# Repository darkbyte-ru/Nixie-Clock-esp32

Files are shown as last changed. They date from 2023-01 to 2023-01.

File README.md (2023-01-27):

# Idea

Original Nixie Clock KIT board contain **STM8S** (STM8S003F3) MCU, **74HC595** (SNx4HC595) shift registers, **ULN2003** darlington drivers, **DS3231** RTC with battery and plexiglass front-back covers. Also there are two buttons for setting the time and change some settings, which are resets after power cycle. 

First thought to keep an MCU and add external GPS/WiFi module to be able to sync time. But then I thought that I could simplify the task a little and completely replace MCU with an ESP32. S2 mini board perfectly fit for size and mounting holes. So a soldered out STM8 MCU and connect ESP32 board using lacquered copper wires.

# In-the-box picture

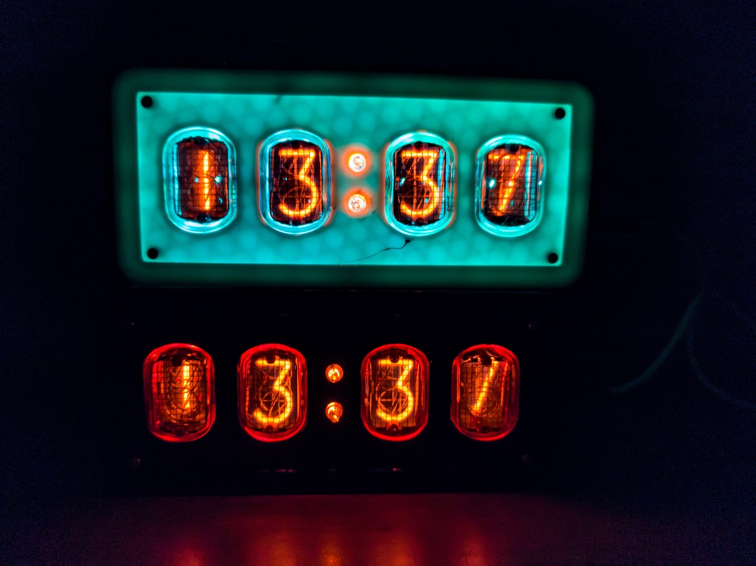
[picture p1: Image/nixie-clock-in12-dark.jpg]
nixie-stm8-pinout


# Hardware

- Nixie Clock IN12 DIY KIT (NixieClock_IN12 v4.2 board from [aliexpress](https://aliexpress.ru/wholesale?SearchText=nixie+clock+in12))
- IN-12 tubes (4pcs) with digits
- 3D printed case (I used [this one](https://www.printables.com/model/69286-in-12-nixie-clock-by-delucalabs))
- WeMos/Lolin S2 MINI ESP32 board
- RCWL-0516 microwave motion sensor

# Assembly

After researching original connection scheme, prepared next pinout: 

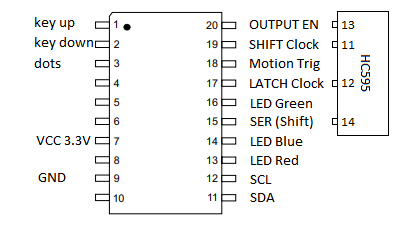
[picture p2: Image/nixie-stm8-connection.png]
nixie-stm8-pinout


I connected the most inputs to the one side of esp32 board and only KEYs wires goes to GPIO10 & 12. Used by me GPIOs can be found in the config.h file.

For test purpose I also connected 5V bus from ESP32 with 5V input of nixie board. Without that tube did not powered up when the only esp board powered.

To extend lamp life and save some electricity there is also **RCWL-0516** microwave motion sensor added (powered from 5V bus). By default it switch-off the tubes after 30 seconds of inactivity.

By default **DOTs** driven via separate transistor, but HC595 registers has left couple unused outputs, so thats possible to connect them there. There is also only one HC595 have connected **Output Enable** pin to MCU, on all other registers that pin just grounded.

Insides looks a bit [ugly](https://github.com/darkbyte-ru/Nixie-Clock-esp32/blob/main/Image/heart-transplant.jpg), but who will see it? 🤷

# Software

Library dependencies: [NTPClient](https://github.com/arduino-libraries/NTPClient) and [ArduinoOTA](https://github.com/espressif/arduino-esp32/tree/master/libraries/ArduinoOTA).

Currently Wi-Fi connection required to startup (but having RTC onboard with backup battery allows to skip this step in feature), so make sure to supply correct Wi-Fi creds in the config.h. While connecting backlight color will be **RED** and timer countdown from 10. If no connection happens - esp reboots. 

After connecting to wireless network clocks will try to sync time with default NTP server (pool.ntp.org). While that backlight color changes to **BLUE**. If NTP server accessable - new time writes to RTC. If timeout occur - this step skipped for now and will be retried after 30 seconds.

Regardless of the previous step result clock will request current time from RTC every minute and output that via nixie tubes. To prevent nixie poisoning before each update there will be scroll through all nixie segments.

# TODO

- Some functional logic for buttons (backlight color change?)
- Failback access point to be able so setup WiFI creds
- Make Wi-Fi connection optional and in the background if RTC running
- Use NTP server from DHCP advertisement instead of default if failed

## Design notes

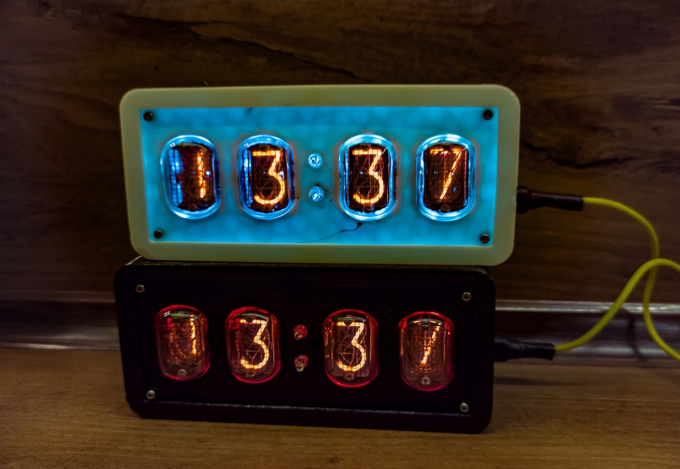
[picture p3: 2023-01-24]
Image/nixie-clock-in12-light.jpg

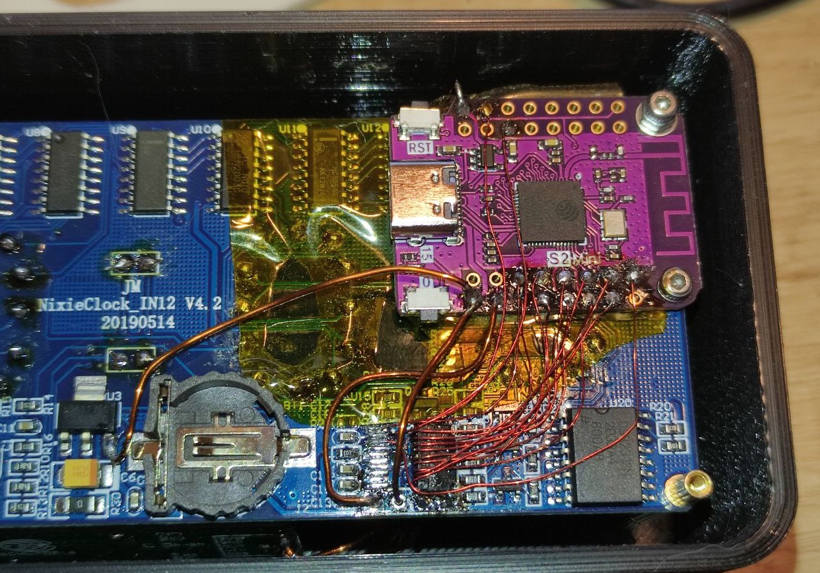
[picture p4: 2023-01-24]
Image/heart-transplant.jpg

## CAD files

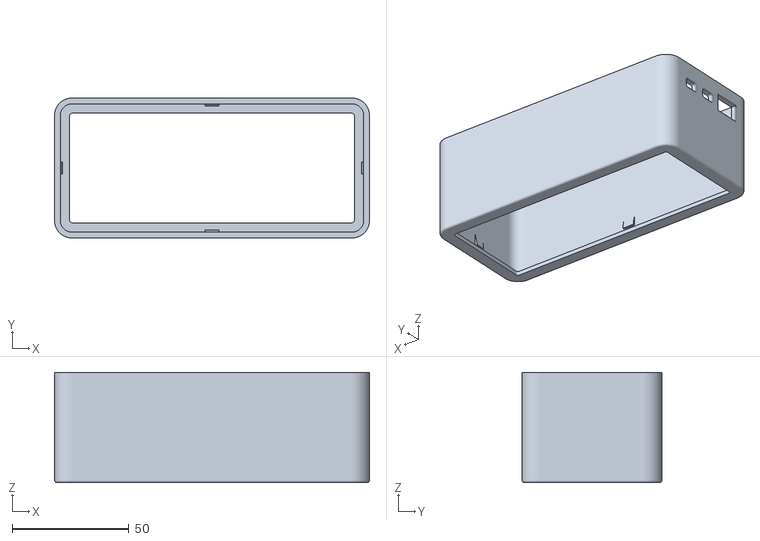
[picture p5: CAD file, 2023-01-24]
Case-stl/nixieLDL_v2_Body_3mm.stl
135.0 x 60.0 x 47.2

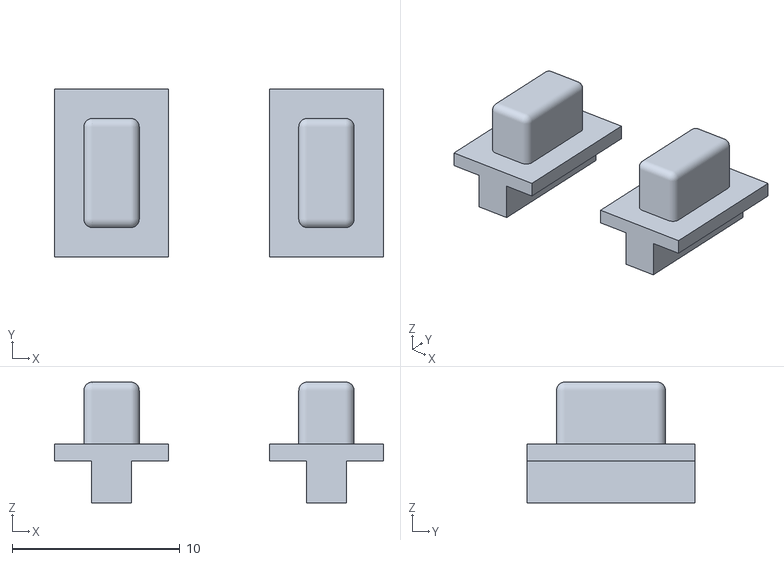
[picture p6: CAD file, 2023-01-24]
Case-stl/nixieLDL_v2_Buttons.stl
19.6 x 10.0 x 7.20

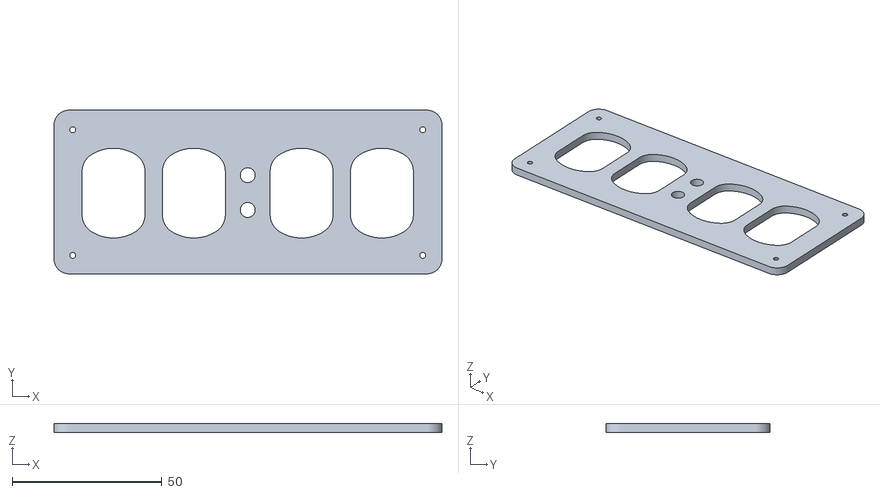
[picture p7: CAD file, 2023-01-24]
Case-stl/nixieLDL_v2_FrontPanel_3mm.stl
129.7 x 54.7 x 3.00

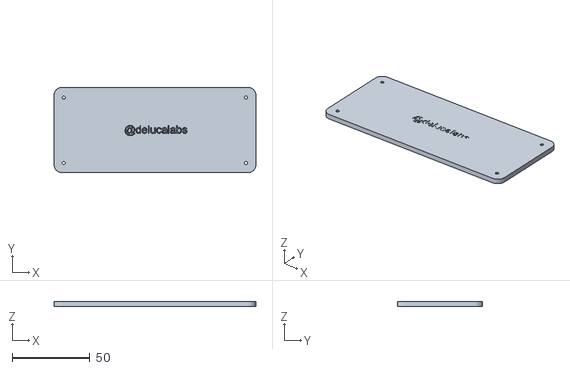
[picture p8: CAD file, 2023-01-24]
Case-stl/nixieLDL_v2_BackPanel_3mm.stl
129.7 x 54.7 x 3.00

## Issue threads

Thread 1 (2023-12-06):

ULN2003 max voltage problem

JDat, 2023-12-06:
Just a note from electronic engineer.

ULN2003 drivers are not suitable for nixies. Max voltage for ULN2003 is 50 volts only, while nixie drivers need to handle 150 or more voltage. Actually drivers need to handle full nixie supply voltage. ULN2003 kinda work, but there is chance to damage drivers.

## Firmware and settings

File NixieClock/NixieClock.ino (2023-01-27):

#include <Wire.h>
#include <WiFi.h>

#include <NTPClient.h>
#include <WiFiUdp.h>

#include <ESPmDNS.h>
#include <ArduinoOTA.h>

WiFiUDP ntpUDP;
NTPClient timeClient(ntpUDP);

byte keyUpPressed = 0;
byte keyDownPressed = 0;
byte motionSensorTriggered = 0;
unsigned int motionSensorLag = 0;

#include "config.h"
#include "helpers.h"
#include "workers.h"

void IRAM_ATTR ISR_KEY_UP() {
  keyUpPressed++;
}

void IRAM_ATTR ISR_KEY_DOWN() {
  keyDownPressed++;
}

void setup() 
{
  Serial.begin(115200);
  Serial.println("setup()");
  randomSeed(analogRead(0));

  xTaskCreate(DotsTask, "DotsTask", 10000, NULL, 1, &hDotsTask);
  
  nixieTubesOn = true;

  //RGB led attach
  ledcAttachPin(BL_R, 1);
  ledcAttachPin(BL_G, 2);
  ledcAttachPin(BL_B, 3);

  ledcSetup(1, PWM_FREQUENCY, PWM_RESOLUTION);
  ledcSetup(2, PWM_FREQUENCY, PWM_RESOLUTION);
  ledcSetup(3, PWM_FREQUENCY, PWM_RESOLUTION);

  ledsBrightness = 99;
  rgbLed(PWM_MAX, 0, 0); //RED backlight indicate initial step

  //Nixie registers
  pinMode(REG_OUTPUT, OUTPUT);//only one register connected there
  pinMode(REG_DATA, OUTPUT); 
  pinMode(REG_SHIFT, OUTPUT);
  pinMode(REG_LATCH, OUTPUT);

  //Keys and motion inputs 
  pinMode(KEY_UP, INPUT_PULLUP);
  pinMode(KEY_DOWN, INPUT_PULLUP);
  pinMode(MOTION_SENSOR, INPUT_PULLDOWN);
  
  attachInterrupt(KEY_UP, ISR_KEY_UP, FALLING);
  attachInterrupt(KEY_DOWN, ISR_KEY_DOWN, FALLING);
  
  //DS3231 RTC via i2c
  Wire.begin(RTC_SDA, RTC_SCL);

  Serial.println("WiFi.begin()");
  WiFi.begin(ssid, password);

  //TODO: if RTC running - skip wifi dependency and delay NTP update
  int countdown = 10;
  while (WiFi.status() != WL_CONNECTED) {
    NixieDisplay(countdown, countdown, countdown, countdown);
    if(!countdown--){
      Serial.println("No wifi, reboots now");
      //TODO: failback AP
      ESP.restart();
    }
    delay(1000);
    Serial.print(".");
  }
  rgbLed(0, PWM_MAX, 0); //GREEN backlight - WiFi connected

  //10 disables all nixie outputs
  NixieDisplay(10, 10, 10, 10);

  xTaskCreate(OTATask, "OTATask", 10000, NULL, 5, &hOTATask);

  rgbLed(0, 0, PWM_MAX); //BLUE backlight - init almost done

  //Inits NTP client and update RTC counters via that
  Serial.println("timeClient.begin()");
  timeClient.begin();
  timeClient.setTimeOffset(TIMEZONE_OFFSET);
  updateRTC();

  xTaskCreate(ButtonsTask, "ButtonsTask", 10000, NULL, 100, &hButtonsTask);
  xTaskCreate(ClockTask, "ClockTask", 10000, NULL, 10, &hClockTask);

  xTaskCreate(MotionSensTask, "MotionSensTask", 10000, NULL, 100, &hMotionSensTask);
  xTaskCreate(BacklightTask, "BacklightTask", 10000, NULL, 100, &hBacklightTask);

/*
  xTaskCreate([](void*) -> void { 
    for(;;){
      rgbFade();
      vTaskDelay(30);
    }
  }, "BacklightColor", 10000, NULL, 100, &hBacklightColorTask);
*/
  
}

void loop() 
{
  //delete built-in task 
  vTaskDelete(nullptr);
}

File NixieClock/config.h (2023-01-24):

const char* ssid     = "HomeWiFi";
const char* password = "1234567890";

//const char* ap_ssid     = "NixieClock";
//const char* ap_password = "1234567890";

//Inputs GPIO
#define KEY_UP 10
#define KEY_DOWN 12
#define MOTION_SENSOR 21

//RGB backlight leds 
#define BL_R 35
#define BL_G 34
#define BL_B 36

//Nixie shift registers 
#define REG_SHIFT 16
#define REG_OUTPUT 17
#define REG_LATCH 18
#define REG_DATA 33

//DS3231 clock connected via i2c
#define RTC_SDA 37
#define RTC_SCL 38
#define DS3231_ADDRESS 0x68

//GMT+05
#define TIMEZONE_OFFSET 5 * 60*60

//Neon DOT leds
#define NIX_DOT 40
#define DOTS_INTERVAL 500

//disable tubes and backlight after 30sec (100*300)
#define motionCheckPer 100
#define motionSensorLagLimit 300

//decay in 1sec (100 steps of brightness in 10ms resolution) 
#define backlightStepPer 10

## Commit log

2023-01-24 little fix
    for connection diagram
    +random depoisoning method
    [helpers.h, workers.h]
2023-01-26 RTOS tasks instead of timers
    for some tasks
2023-01-27 RTOS tasks instead of timers
    also for(;;) instead of while(1) because one letter shorter
    [NixieClock.ino, helpers.h, workers.h]
